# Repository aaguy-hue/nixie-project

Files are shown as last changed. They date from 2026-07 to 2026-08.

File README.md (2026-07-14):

# Nixie Project
This is a collection of all the PCB designs and software I've written for an STM32-based
Nixie tube clock.

Nixie tubes are some really neat old displays from back during the 1960s, though they kept being
used in the USSR for quite a while, so you can find them on ebay being sold from various
post-soviet states. They have a pretty cool signature orange-ish glow that looks cool, so
I wanted to make a digital clock with them.

Note: Nixies operate at high voltage (albeit very low current), so make sure to exercise caution
when working with them!

<br>

Online image of a Nixie clock (hopefully once mine is built I can replace this image with my own!)


## Project Structure
This is a bit unorganized and will likely soon be refactored, but at the moment this is the structure:
- 3D_Models: 3D models used in the PCBs (the NCH8200HV and my Micro USB connector)
- NixieProject.pretty: Footprint library
- nixies-us.pretty: A footprint library of various Nixie tubes
- nixies-us.mod: Schematic symbols for different Nixie tubes
- Single Tube Board: A PCB to power a single Nixie tube
- software: Software for the various projects
  - nixie_simple: Software for breadboard experiments
  - single_nixie: Software for single Nixie tube PCB
- symbols: Custom schematic symbols

## Part descriptions
- STM32F103C8T6: Microcontroller controlling the tubes
- NCH8200HV: Voltage booster, input 2.5-15V, output 170V
- AMS1117-3.3: 3.3V linear regulator
- K155ID1: BCD-to-decimal decoder

The rest of the parts should be pretty self-explanatory.

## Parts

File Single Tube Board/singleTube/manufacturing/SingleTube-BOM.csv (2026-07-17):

Comment | Designator | Footprint | JLCPCB Part #
8p | C10,C11 | Capacitor_SMD:C_0402_1005Metric | C1578
20p | C12,C13 | Capacitor_SMD:C_0402_1005Metric | C1554
100n | C1,C2,C3,C4,C8,C9 | Capacitor_SMD:C_0402_1005Metric | C1525
10u | C5 | Capacitor_SMD:C_0603_1608Metric | C19702
22u | C14,C15 | Capacitor_SMD:C_0805_2012Metric | C45783
1k5 | R1,R3 | Resistor_SMD:R_0402_1005Metric | C25867
4k7 | R11,R12 | Resistor_SMD:R_1206_3216Metric | C17936
10k | R2 | Resistor_SMD:R_0402_1005Metric | C173683
10k | R4 | Resistor_SMD:R_1206_3216Metric | C17902
30k | R7,R10 | Resistor_SMD:R_1206_3216Metric | C17999
32.768KHz | Y2 | Crystal:Crystal_SMD_2520-4Pin_2.5x2.0mm | C21547573
1M | R13 | Resistor_SMD:R_1206_3216Metric | C17927
16MHz | Y1 | Crystal:Crystal_SMD_3225-4Pin_3.2x2.5mm | C13738
AMS1117-3.3 | U3 | Package_TO_SOT_SMD:SOT-223-3_TabPin2 | C6186
Conn_01x04_Pin | J2 | Connector_PinHeader_2.54mm:PinHeader_1x04_P2.54mm_Vertical | C5116483
MMBTA42 | Q1,Q2 | Package_TO_SOT_SMD:SOT-23 | C181172
RED | D1 | LED_SMD:LED_0603_1608Metric | C2286
STM32F103C8T6 | U1 | Package_QFP:LQFP-48_7x7mm_P0.5mm | C8734
SW_SPDT | SW1 | Button_Switch_THT:SW_E-Switch_EG1224_SPDT_Angled | C273395
USB_B_Micro | J1 | Connector_USB:USB_Micro-B_XKB_U254-051T-4BH83-F1S | C397452

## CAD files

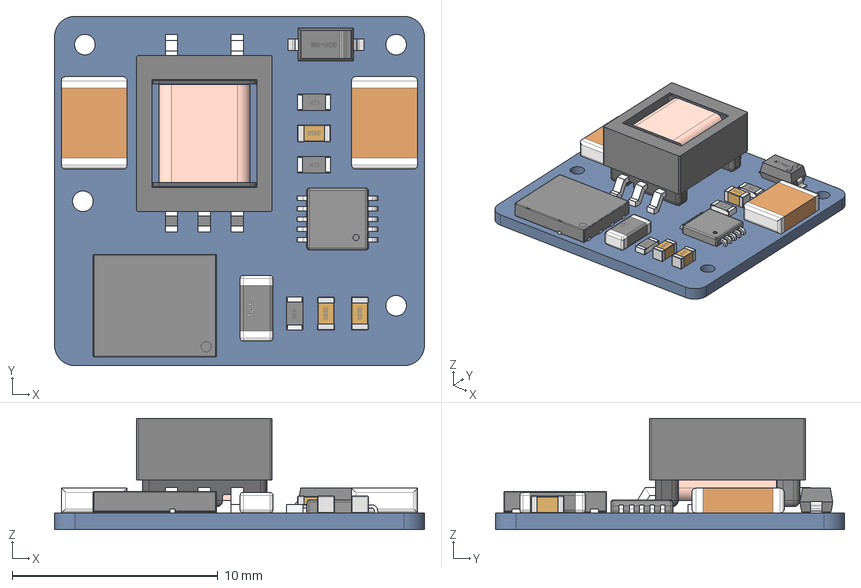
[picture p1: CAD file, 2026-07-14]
3D_Models/NCH8200HV.step
18.0 x 17.0 x 5.42 mm
Board
SW3dPS-uMAX10_Part_141
SW3dPS-uMAX10_Part_2291
SW3dPS-uMAX10_Part_1911
SW3dPS-uMAX10_Part_1987
SW3dPS-uMAX10_Part_1492
SW3dPS-uMAX10_Part_2139
SW3dPS-uMAX10_Part_2443
SW3dPS-uMAX10_Part_1799
SW3dPS-uMAX10_Part_2367
SW3dPS-uMAX10_Part_2215
SW3dPS-uMAX10_Part_2063
TTRN-060S
R_0603 x 3
LOGO? x 6
1206R2
User_Library-SON8-5x6mm
SOD-123
LOGOﾔｲ｣ｭ｣ｰ.｣ｳ
1812C x 2
C_0603 x 3

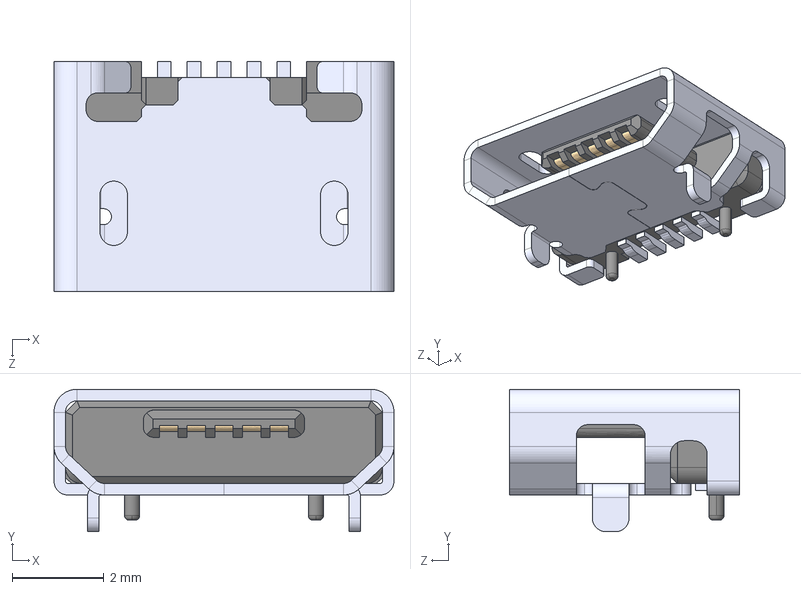
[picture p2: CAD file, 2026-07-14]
3D_Models/U254-051T-4BH83-F1S--3DModel-STEP-510211.STEP
7.40 x 3.10 x 5.00 mm

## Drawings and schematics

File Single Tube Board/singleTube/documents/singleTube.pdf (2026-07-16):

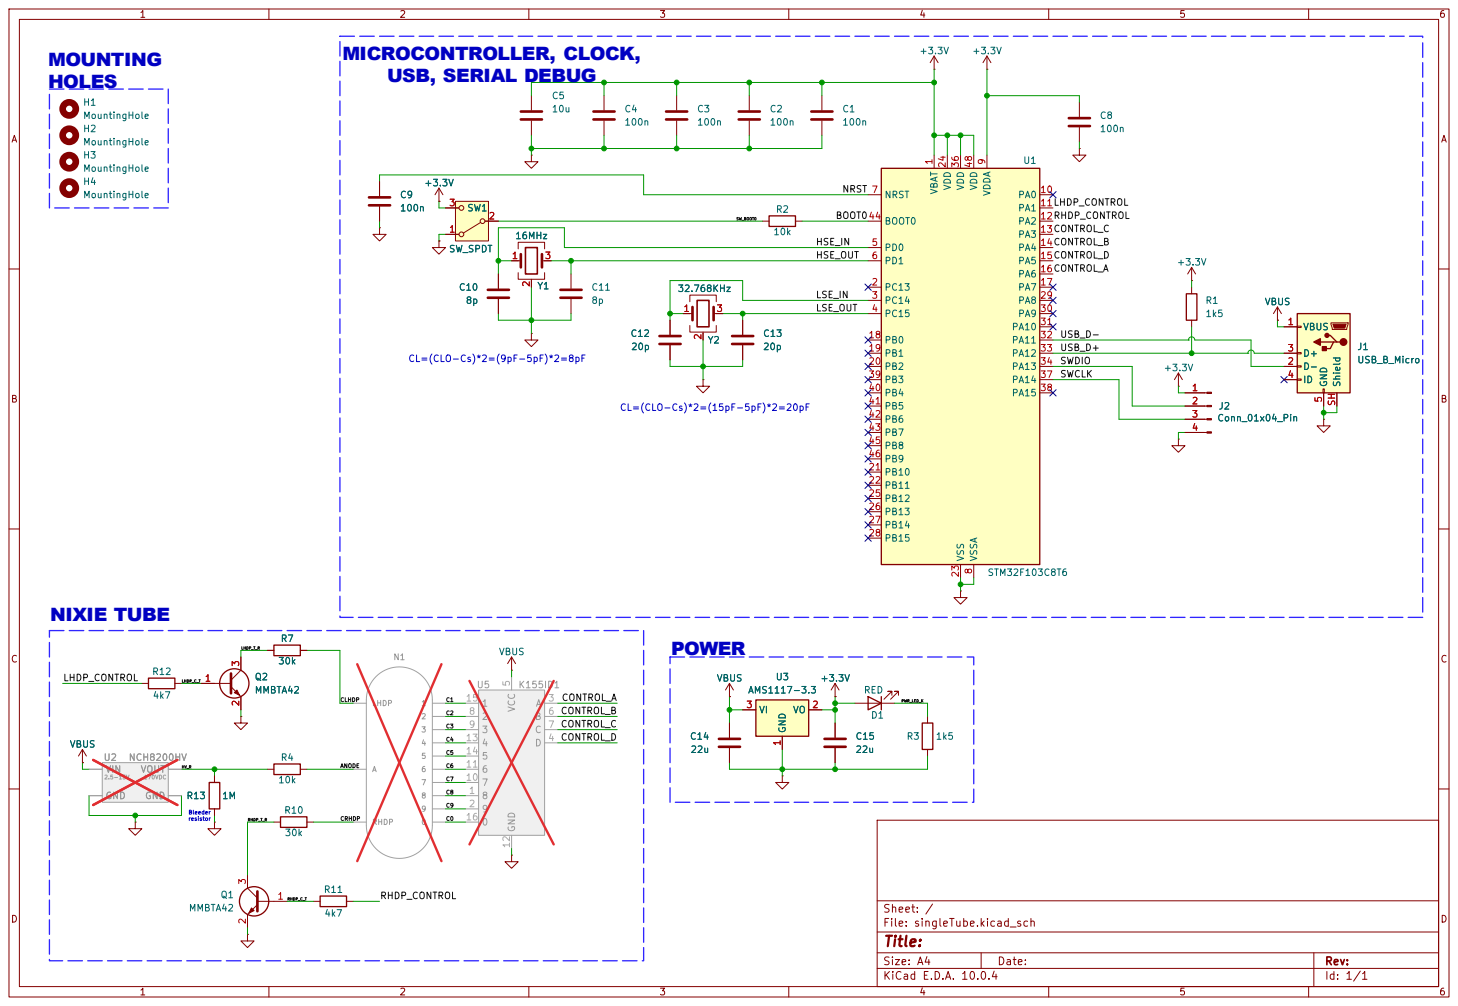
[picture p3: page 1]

Size: A4 | Rev:
KiCad E.D.A. 10.0.4 | Id: 1/1

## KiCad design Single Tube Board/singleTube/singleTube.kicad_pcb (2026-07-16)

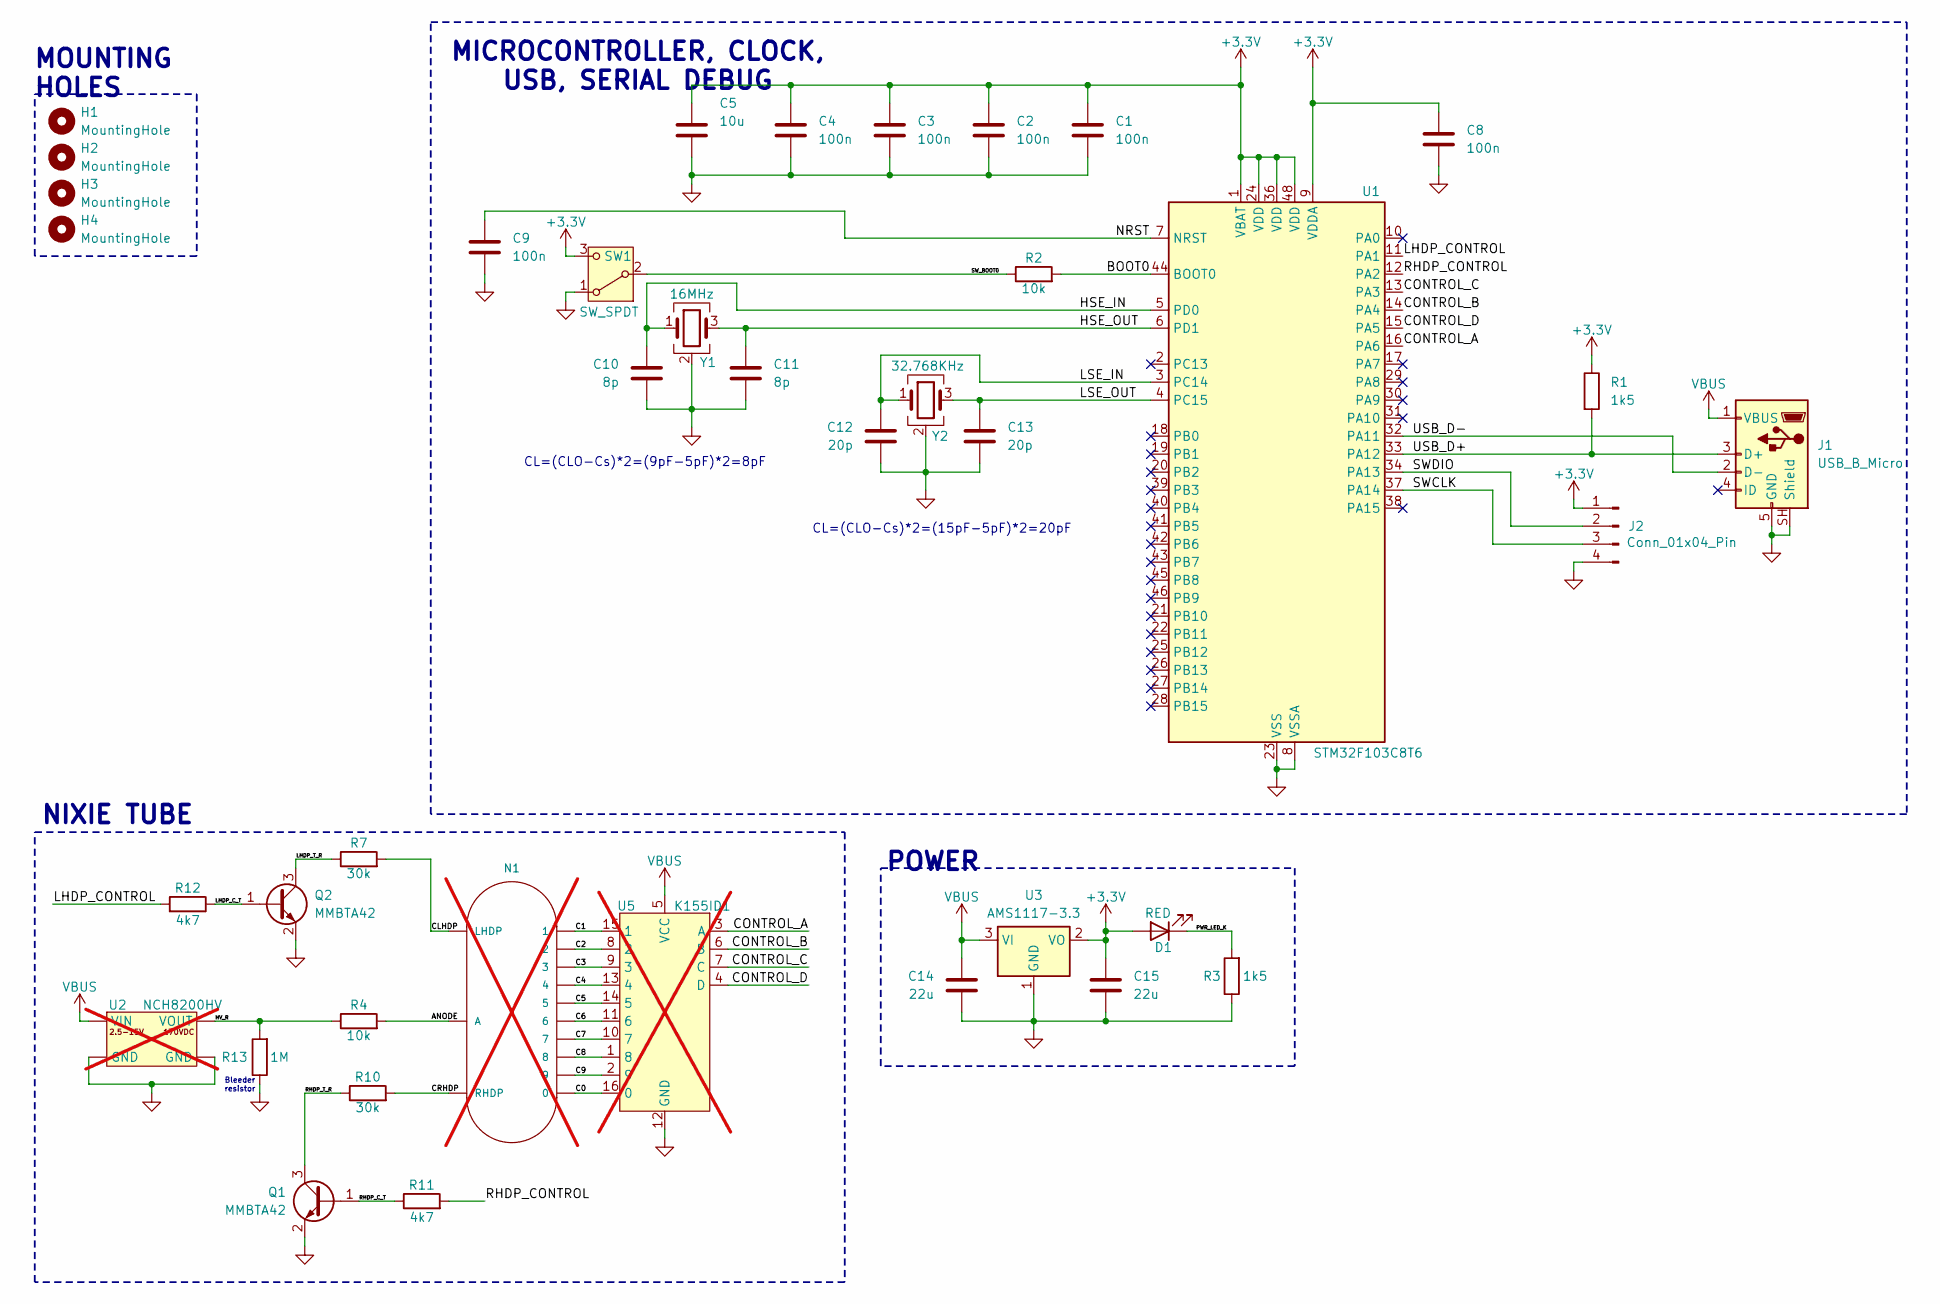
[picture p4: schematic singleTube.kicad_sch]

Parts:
C1, C2, C3, C4, C8, C9: 100n; C_0402_1005Metric; JLCPCB Part # C1525
C5: 10u; C_0603_1608Metric; JLCPCB Part # C19702
C10, C11: 8p; C_0402_1005Metric; JLCPCB Part # C1578
C12, C13: 20p; C_0402_1005Metric; JLCPCB Part # C1554
C14, C15: 22u; C_0805_2012Metric; JLCPCB Part # C45783
D1: RED; LED_0603_1608Metric; JLCPCB Part # C2286
H1, H2, H3, H4: MountingHole; MountingHole_3.2mm_M3
J1: USB_B_Micro; USB_Micro-B_XKB_U254-051T-4BH83-F1S; JLCPCB Part # C397452
J2: Conn_01x04_Pin; PinHeader_1x04_P2.54mm_Vertical; JLCPCB Part # C5116483
N1: IN-14; nixies-us-IN-14; not fitted
Q1, Q2: MMBTA42; SOT-23; JLCPCB Part # C118557
R1, R3: 1k5; R_0402_1005Metric; JLCPCB Part # C25867
R2: 10k; R_0402_1005Metric; JLCPCB Part # C25744
R4: 10k; R_1206_3216Metric; JLCPCB Part # C17902
R7, R10: 30k; R_1206_3216Metric; JLCPCB Part # C17999
R11, R12: 4k7; R_1206_3216Metric; JLCPCB Part # C17936
R13: 1M; R_1206_3216Metric; JLCPCB Part # C17927
SW1: SW_SPDT; SW_E-Switch_EG1224_SPDT_Angled; JLCPCB Part # C273395
U1: STM32F103C8T6; LQFP-48_7x7mm_P0.5mm; JLCPCB Part # C8734
U2: NCH8200HV; not fitted
U3: AMS1117-3.3; SOT-223-3_TabPin2; JLCPCB Part # C6186
U5: K155ID1; SN74141N; not fitted
Y1: 16MHz; Crystal_SMD_3225-4Pin_3.2x2.5mm; JLCPCB Part # C13738
Y2: 32.768KHz; Crystal_SMD_2520-4Pin_2.5x2.0mm; JLCPCB Part # C21547573

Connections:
+3.3V: C1.1, C2.1, C3.1, C4.1, C5.1, C8.1, C15.1, D1.2 (A), J2.1, R1.1, SW1.3 (C), U1.1 (VBAT), U1.9 (VDDA), U1.24 (VDD), U1.36 (VDD), U1.48 (VDD), U3.2 (VO)
/ANODE: N1.A, R4.2
/BOOT0: R2.2, U1.44 (BOOT0)
/C0: N1.0, U5.16 (0)
/C1: N1.1, U5.15 (1)
/C2: N1.2, U5.8 (2)
/C3: N1.3, U5.9 (3)
/C4: N1.4, U5.13 (4)
/C5: N1.5, U5.14 (5)
/C6: N1.6, U5.11 (6)
/C7: N1.7, U5.10 (7)
/C8: N1.8, U5.1 (8)
/C9: N1.9, U5.2 (9)
/CLHDP: N1.LHDP, R7.2
/CONTROL_A: U1.16 (PA6), U5.3 (A)
/CONTROL_B: U1.14 (PA4), U5.6 (B)
/CONTROL_C: U1.13 (PA3), U5.7 (C)
/CONTROL_D: U1.15 (PA5), U5.4 (D)
/CRHDP: N1.RHDP, R10.2
/HSE_IN: C10.1, U1.5 (PD0), Y1.1
/HSE_OUT: C11.1, U1.6 (PD1), Y1.3
/HV_R: R4.1, R13.2, U2.2 (VOUT)
/LHDP_CONTROL: R12.2, U1.11 (PA1)
/LHDP_C_T: Q2.1 (B), R12.1
/LHDP_T_R: Q2.3 (C), R7.1
/LSE_IN: C12.1, U1.3 (PC14), Y2.1
/LSE_OUT: C13.1, U1.4 (PC15), Y2.3
/NRST: C9.1, U1.7 (NRST)
/PWR_LED_K: D1.1 (K), R3.2
/RHDP_CONTROL: R11.2, U1.12 (PA2)
/RHDP_C_T: Q1.1 (B), R11.1
/RHDP_T_R: Q1.3 (C), R10.1
/SWCLK: J2.3, U1.37 (PA14)
/SWDIO: J2.2, U1.34 (PA13)
/SW_BOOT0: R2.1, SW1.2 (B)
/USB_D+: J1.3 (D+), R1.2, U1.33 (PA12)
/USB_D-: J1.2 (D-), U1.32 (PA11)
GND: C1.2, C2.2, C3.2, C4.2, C5.2, C8.2, C9.2, C10.2, C11.2, C12.2, C13.2, C14.2, C15.2, J1.5 (GND), J1.SH (Shield), J2.4, Q1.2 (E), Q2.2 (E), R3.1, R13.1, SW1.1 (A), U1.8 (VSSA), U1.23 (VSS), U1.35 (VSS), U1.47 (VSS), U2.3 (GND), U2.4 (GND), U3.1 (GND), U5.12 (GND), Y1.2 (G), Y1.4 (G), Y2.2 (G), Y2.4 (G)
VBUS: C14.1, J1.1 (VBUS), U2.1 (VIN), U3.3 (VI), U5.5 (VCC)

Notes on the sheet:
NIXIE TUBE
MOUNTING HOLES
Bleeder resistor
CL=(CLO-Cs)*2=(9pF-5pF)*2=8pF
CL=(CLO-Cs)*2=(15pF-5pF)*2=20pF
POWER
MICROCONTROLLER, CLOCK, USB, SERIAL DEBUG

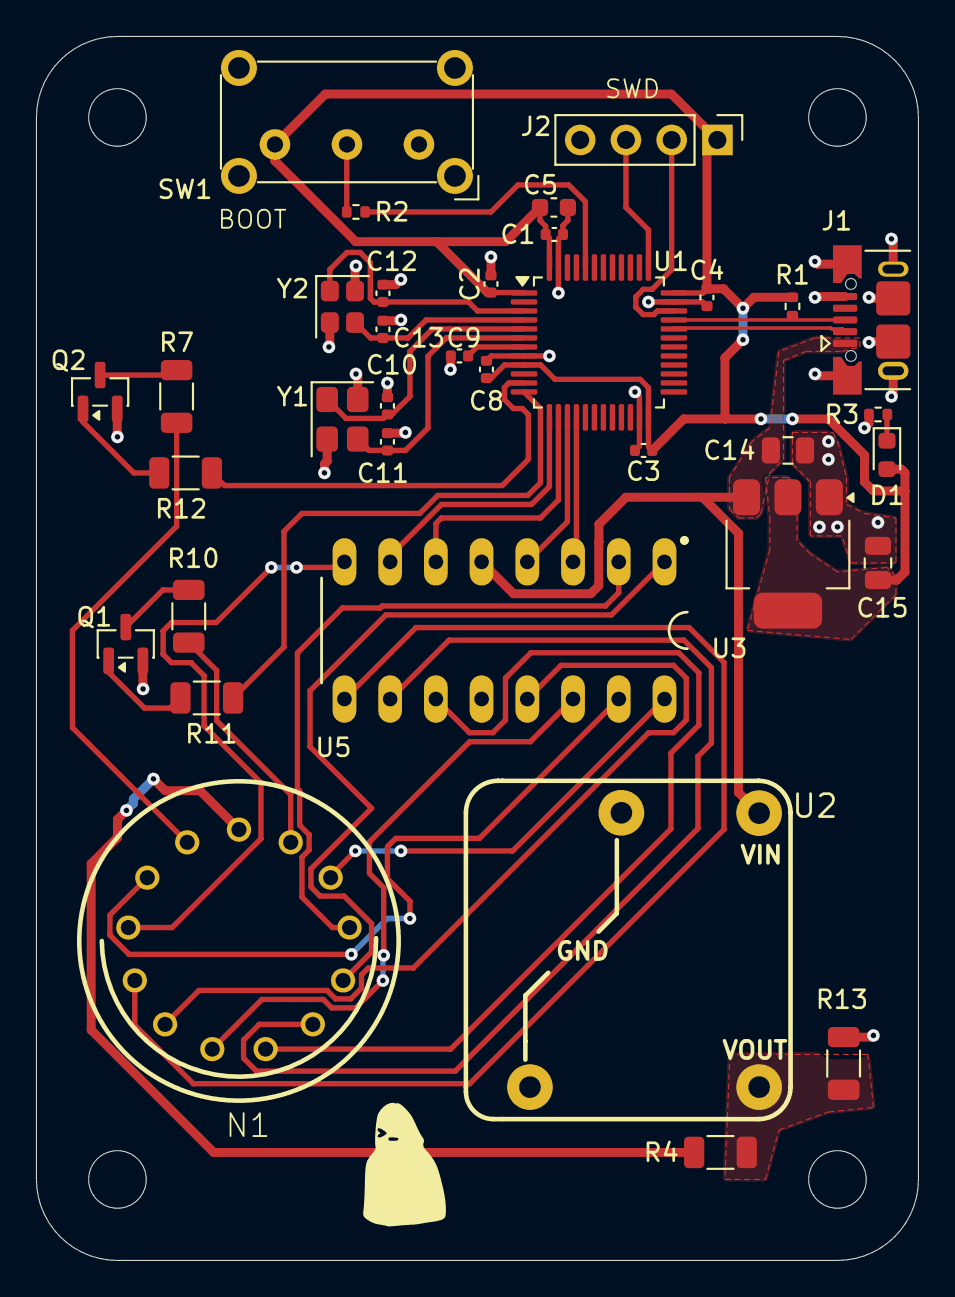
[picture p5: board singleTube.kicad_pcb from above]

Board: 2 copper layers, 49.0 x 68.0 mm, 39 parts (0 on the bottom side), 39 nets.

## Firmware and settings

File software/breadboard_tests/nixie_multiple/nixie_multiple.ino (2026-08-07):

const unsigned long intervalMillis = 50;
unsigned long previousMillis = 0;

typedef struct {
  int A, B, C, D;
  char num;
  bool scroll;
} Tube;

// although I wish I could list in pin order, C++, unlike C, requires designated initializers to be in order
Tube Tube1 = {
  .A = 9,
  .B = 11,
  .C = 12,
  .D = 10,
  .num = 10,
  .scroll = false
};

Tube Tube2 = {
  .A = 8,
  .B = 6,
  .C = 5,
  .D = 7,
  .num = 10,
  .scroll = false
};

// the digit 4 is not connected here bc the leads were too short to connect to my jumper, so I just left it unconnected
Tube Tube3 = {
  .A = 4,
  .B = 2,
  .C = A7,
  .D = 3,
  .num = 10,
  .scroll = false
};

// the digits 9 and 0 are not connected
Tube Tube4 = {
  .A = A0,
  .B = A2,
  .C = A3,
  .D = A1,
  .num = 10,
  .scroll = false
};

Tube tubes[] = {Tube1, Tube2, Tube3, Tube4};


size_t totalTubeCount() {
  return sizeof(tubes)/sizeof(tubes[0]);
}

void initializeTubePins(Tube *tube) {
  pinMode(tube->A, OUTPUT);
  pinMode(tube->B, OUTPUT);
  pinMode(tube->C, OUTPUT);
  pinMode(tube->D, OUTPUT);
}

void setup() {
  for (int i = 0; i < totalTubeCount(); i++) {
    initializeTubePins(&tubes[i]);
  }
  
  for (int i = 0; i < totalTubeCount(); i++) {
    updateTube(&tubes[i]);
  }

  Serial.begin(9600);
  Serial.println("Enter a number between 0 and 9 to display on the nixie tube, or '10' to turn it off.");
}

// Write a number to the nixie tube
// Digits above 9 will turn off the nixie tube bc of how the SN74141/K155ID1 works
void updateTube(Tube *tube) {
  // log tube 3's pin states for debugging, pins ABCD
  if (tube == &tubes[2]) {
    Serial.println(String("Digit 3 pins set value: ") + String((int)(tube->num&1)) + String((int)((tube->num>>1)&1)) + String((int)((tube->num>>2)&1)) + String((int)((tube->num>>3)&1)));
  }
  digitalWrite(tube->D, (tube->num >> 3)&1);
  digitalWrite(tube->C, (tube->num >> 2)&1);
  digitalWrite(tube->B, (tube->num >> 1)&1);
  digitalWrite(tube->A, (tube->num     )&1);
}

void readSerialData() {
  if (Serial.available() < 2) return;

  int tube_num = Serial.read();
  int val = Serial.read();

  Tube *tube;
  if (tube_num < 1 || tube_num > totalTubeCount()) {
    return;
  }
  tube = &tubes[tube_num-1];

  if (val == -1) return;
  if (val == 16) {
    tube->scroll = true;
  } else {
    tube->scroll = false;
    // Serial.println("Received value:" + String(val));
    tube->num = (char) val;
    updateTube(tube);
  }
}

void loop() {
  readSerialData();

  Serial.println(String("Digit 3 Number: ") + String((int)Tube3.num));
  Serial.println(String("Digit 3 pins actual value: ") + String(digitalRead(Tube3.A)) + String(digitalRead(Tube3.B)) + String(digitalRead(Tube3.C)) + String(digitalRead(Tube3.D)));

  updateTube(&tubes[2]);

  unsigned long currentMillis = millis();
  if (currentMillis - previousMillis >= intervalMillis) {
    previousMillis = currentMillis;

    for (int i = 0; i < totalTubeCount(); i++) {
      if (tubes[i].scroll) {
        tubes[i].num = (tubes[i].num+1)%10;
        updateTube(&tubes[i]);
      }
    }
  }
}

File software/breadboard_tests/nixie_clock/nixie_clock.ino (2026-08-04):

#include <mbed.h>
// #include <time.h>
// mbed.h provides functions to get the current time

// note: look into reordering fields for better packing
typedef struct {
  int A, B, C, D;
  char num;
  time_t scrollStart; // on arduino, time_t is an unsigned long int
} Tube;

// although I wish I could list in pin order, C++, unlike C, requires designated initializers to be in order
static Tube Tube1 = {
  .A = 9,
  .B = 11,
  .C = 12,
  .D = 10,
  .num = 10,
  .scrollStart = 0,
};

static Tube Tube2 = {
  .A = 8,
  .B = 6,
  .C = 5,
  .D = 7,
  .num = 10,
  .scrollStart = 0,
};

// the digit 4 is not connected here bc the leads were too short to connect to my jumper, so I just left it unconnected
static Tube Tube3 = {
  .A = 4,
  .B = 2,
  .C = A7,
  .D = 3,
  .scrollStart = 0,
  .num = 10,
};

// the digits 9 and 0 are not connected
static Tube Tube4 = {
  .A = A0,
  .B = A2,
  .C = A3,
  .D = A1,
  .num = 10,
  .scrollStart = 0,
};

static Tube tubes[] = {Tube1, Tube3, Tube4, Tube2};


static size_t totalTubeCount() {
  return sizeof(tubes)/sizeof(tubes[0]);
}

static void initializeTubePins(Tube *tube) {
  pinMode(tube->A, OUTPUT);
  pinMode(tube->B, OUTPUT);
  pinMode(tube->C, OUTPUT);
  pinMode(tube->D, OUTPUT);
}

void setup() {
  for (int i = 0; i < totalTubeCount(); i++) {
    initializeTubePins(&tubes[i]);
  }

  Serial.begin(9600);
}

// Write a number to the nixie tube
// Digits above 9 will turn off the nixie tube bc of how the SN74141/K155ID1 works
static void updateTubeDisplay(Tube *tube) {
  digitalWrite(tube->D, (tube->num >> 3)&1);
  digitalWrite(tube->C, (tube->num >> 2)&1);
  digitalWrite(tube->B, (tube->num >> 1)&1);
  digitalWrite(tube->A, (tube->num     )&1);
}

// over serial, my python program will periodially send the current time (maybe every hour or so) by sending the seconds since the epoch
static void readSerialData() {
  if (!Serial.available()) return;

  String input = Serial.readStringUntil('\n');
  input.trim();

  int time_since_epoch = input.toInt();
  if (time_since_epoch > 0) {
    set_time(time_since_epoch);
  }
}

static void updateTubeNumber(Tube *tube, int new_num) {
  if (!tube->scrollStart) {
    tube->num = new_num;
  } else {
    tube->num = (tube->num + 1) % 10;

    // scroll for 2 sec
    if (time(NULL) - tube->scrollStart >= 2) {
      tube->scrollStart = 0;
    }
  }
}

// based on time since epoch set tube digits to the current time in HH:MM format
static void updateTubeNumbers() {
    time_t current_time = time(NULL);
    struct tm *time_info = localtime(&current_time);
    
    int hour = time_info->tm_hour;
    int minute = time_info->tm_min;

    // every 2 minutes, scroll tubes for anti-cathode poisoning
    if (minute % 2 == 0 && time_info->tm_sec == 0) {
        for (int i = 0; i < totalTubeCount(); i++) {
            tubes[i].scrollStart = current_time;
        }
    }
    
    updateTubeNumber(&tubes[0], hour / 10);      // tens place of hour
    updateTubeNumber(&tubes[1], hour % 10);      // ones place of hour
    updateTubeNumber(&tubes[2], minute / 10);    // tens place of minute
    updateTubeNumber(&tubes[3], minute % 10);    // ones place of minute
}

void loop() {
  readSerialData();
  updateTubeNumbers();

  for (int i = 0; i < totalTubeCount(); i++) {
    Tube *tube = &tubes[i];
    updateTubeDisplay(tube);
  }
}

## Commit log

2026-07-15 Finish routing single tube PCB
    [singleTube.kicad_pcb, singleTube.kicad_sch]
2026-07-15 Remove analog filtering, simplify routing
    [singleTube.kicad_pcb, singleTube.kicad_sch]
2026-07-15 Remove unnecessary ground vias
    [singleTube.kicad_pcb]
2026-07-16 Create BOM
    [SingleTube-BOM.csv, singleTube.kicad_pcb, singleTube.kicad_sch]
2026-07-16 generate position file
    [SingleTube-all-pos.csv]
2026-07-16 generate drill file and gerbers
    [SingleTube-B_Cu.gbr, SingleTube-B_Mask.gbr, SingleTube-B_Paste.gbr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]
2026-07-16 zip gerbers/drill file
2026-07-16 update manufacturing files for single tube board
    [SingleTube-BOM.csv, singleTube.kicad_pcb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]
2026-07-17 final updates to BOM during first order
    [SingleTube-BOM.csv]
2026-07-30 Fix showing digits with scroll
    [nixie_serialpicker.ino, serialpicker.py]
2026-07-30 send commands to tube, fix scrolling issues
    [nixie_serialpicker.ino, serialpicker.py]
2026-07-31 three nixie tubes!!!
2026-08-01 4th tube
2026-08-07 working on debugging issues with digit 3
    [nixie_multiple.ino, nixie_serialpicker.ino]
